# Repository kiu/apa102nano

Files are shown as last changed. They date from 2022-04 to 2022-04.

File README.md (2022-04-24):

# apa102nano
I love to play around with adressable [APA102](https://cpldcpu.wordpress.com/2014/08/27/apa102/) LED strips, quickly iterating animations using the Arduino Nano.
But I am tired of wiring power, looking up which pins are SPI and having dangling wires everywhere. Time to have some boards ready for a frustration free out-of-the-box experience.

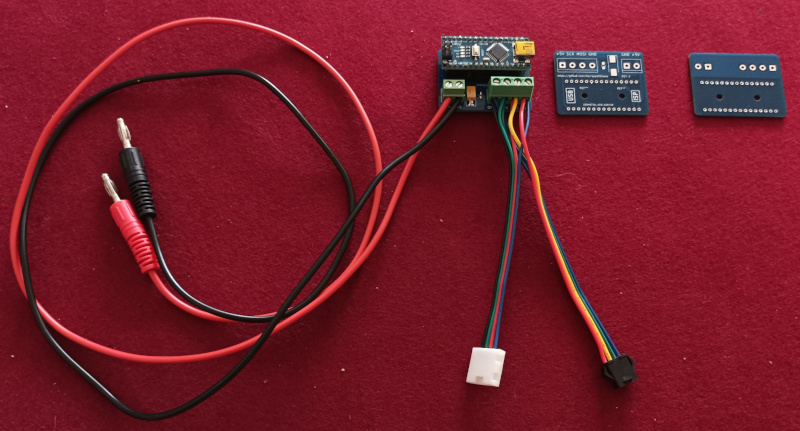
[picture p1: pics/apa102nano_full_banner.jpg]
apa102nano


# Nitty-Gritty Details
Checkout the [pics](https://github.com/kiu/apa102nano/tree/master/pics) and [hardware](https://github.com/kiu/apa102nano/tree/master/rev_a) section including BOM, Schematic, PCB layout, etc.

# Errata
I included mounting holes as an afterthought and forget to hide the silk screen "REF**" designators :/

# License
Creative Commons Attribution-NonCommercial 3.0 Unported (CC BY-NC 3.0)
See LICENSE and https://creativecommons.org/licenses/by-nc/3.0/

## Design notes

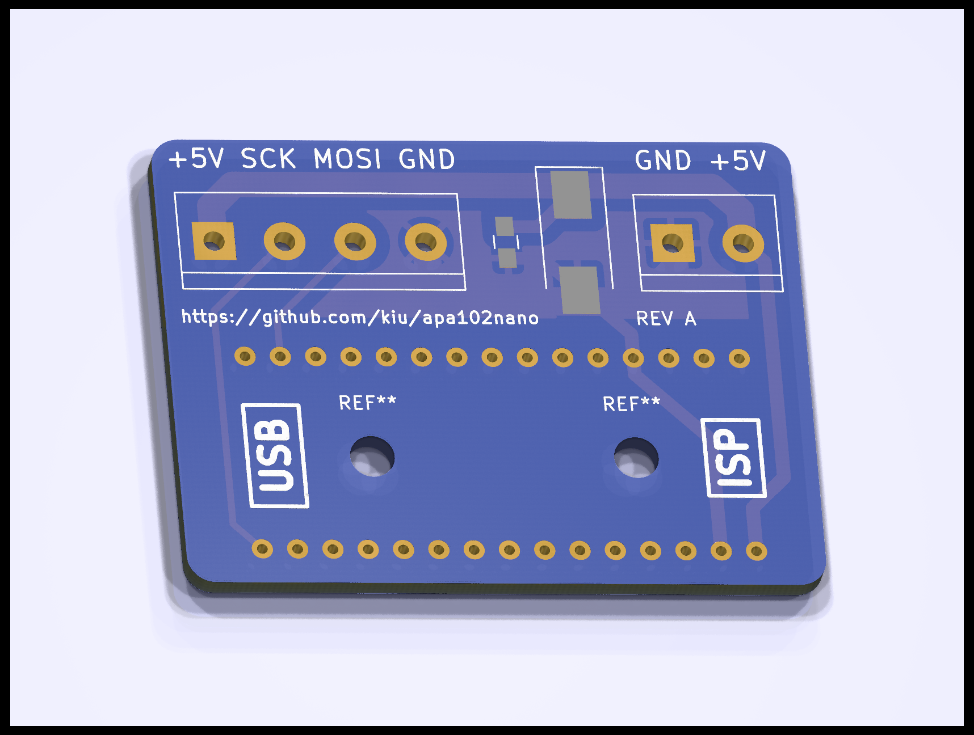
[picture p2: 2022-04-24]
rev_a/hardware/apa102nano-render.png

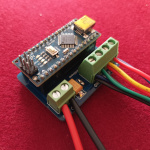
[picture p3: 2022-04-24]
pics/apa102nano_closeup_150x150.jpg

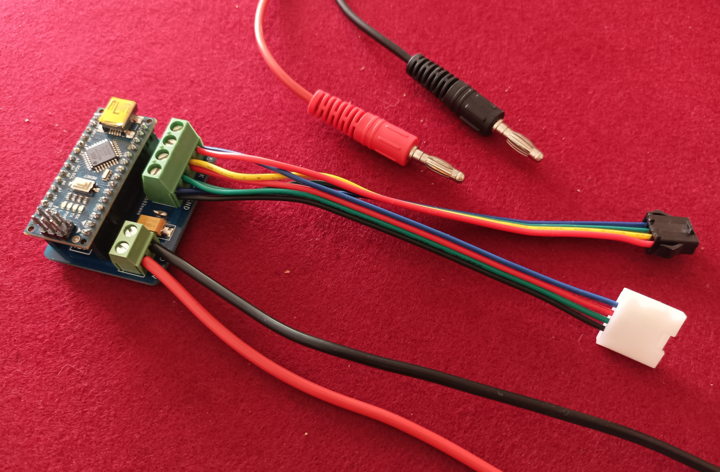
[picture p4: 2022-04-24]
pics/apa102nano_connectors.jpg

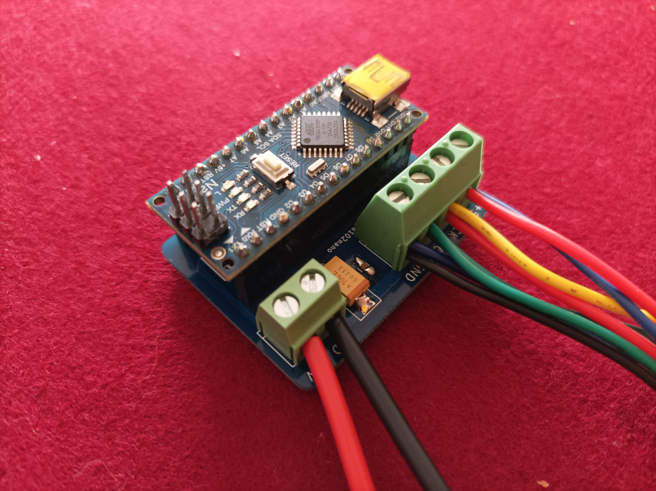
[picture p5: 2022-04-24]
pics/apa102nano_closeup.jpg

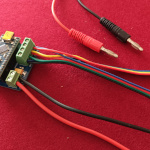
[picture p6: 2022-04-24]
pics/apa102nano_connectors_150x150.jpg

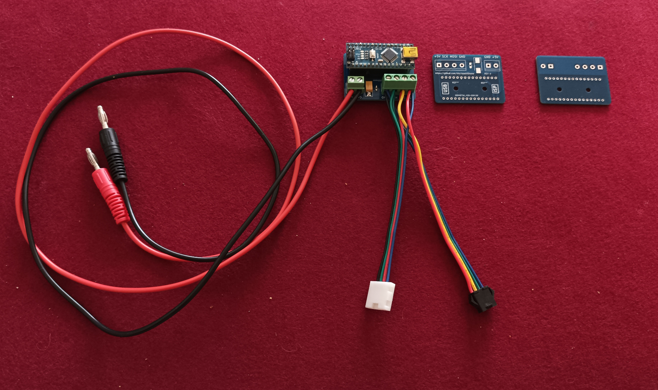
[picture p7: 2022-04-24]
pics/apa102nano_full.jpg

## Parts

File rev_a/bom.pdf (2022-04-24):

BOM

Page 1

Symbol | Description | Req | +VAT | Price | Price (sum) | Provider | ID
| | | | MOQ 10
A1 | Pin Header 1x15 2.54 | 2 | 0 | 0,14 € | 0,27 € | https://www.aliexpress.com | 4000220585291
J1 | Terminal Block 1x02 P5.08 | 1 | 0 | 0,25 € | 0,25 € | http://www.reichelt.de | CTB0509-2
J2 | Terminal Block 1x04 P5.08 | 1 | 0 | 1,54 € | 1,54 € | http://tme.eu | MKDS1.5/4-5.08
C1 | 220uF Tantalum Case D | 1 | 19 | 0,80 € | 0,95 € | http://www.mouser.de | 74-293D227X96R3D2TE3
C2 | 100nF 0805 | 1 | 19 | 0,07 € | 0,08 € | http://www.mouser.de | 710-885012207098
- | PCB 46x35 Blue + Shipping | 1 | 19 | 1,41 € | 1,67 € | https://jlcpcb.com | -

SUM
4,77 €
47,68 €

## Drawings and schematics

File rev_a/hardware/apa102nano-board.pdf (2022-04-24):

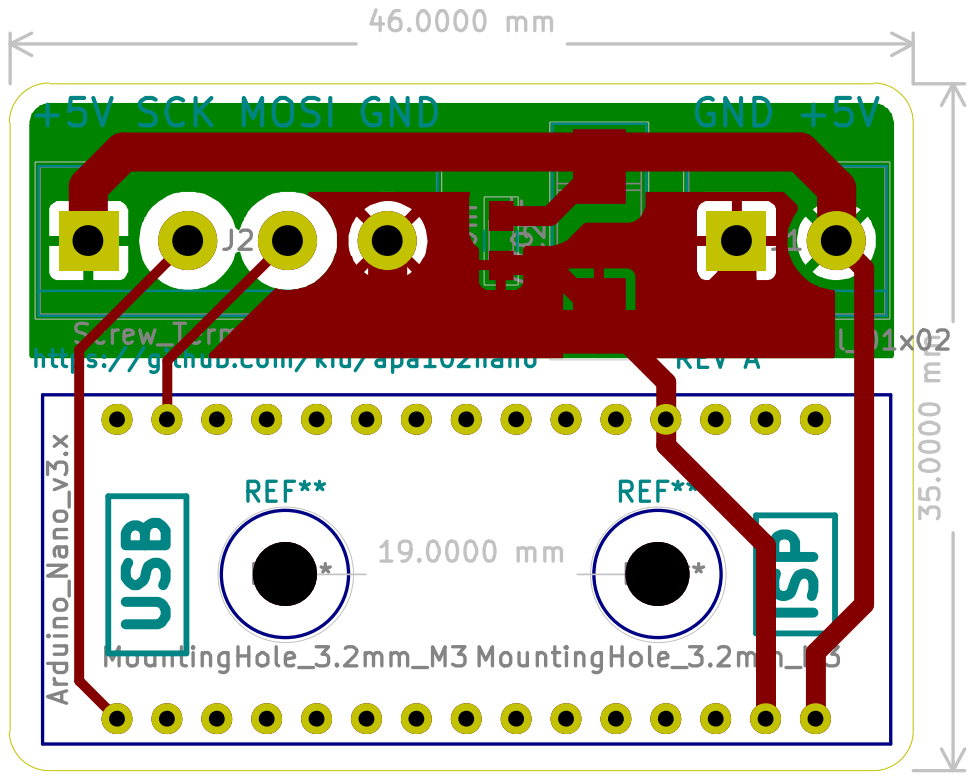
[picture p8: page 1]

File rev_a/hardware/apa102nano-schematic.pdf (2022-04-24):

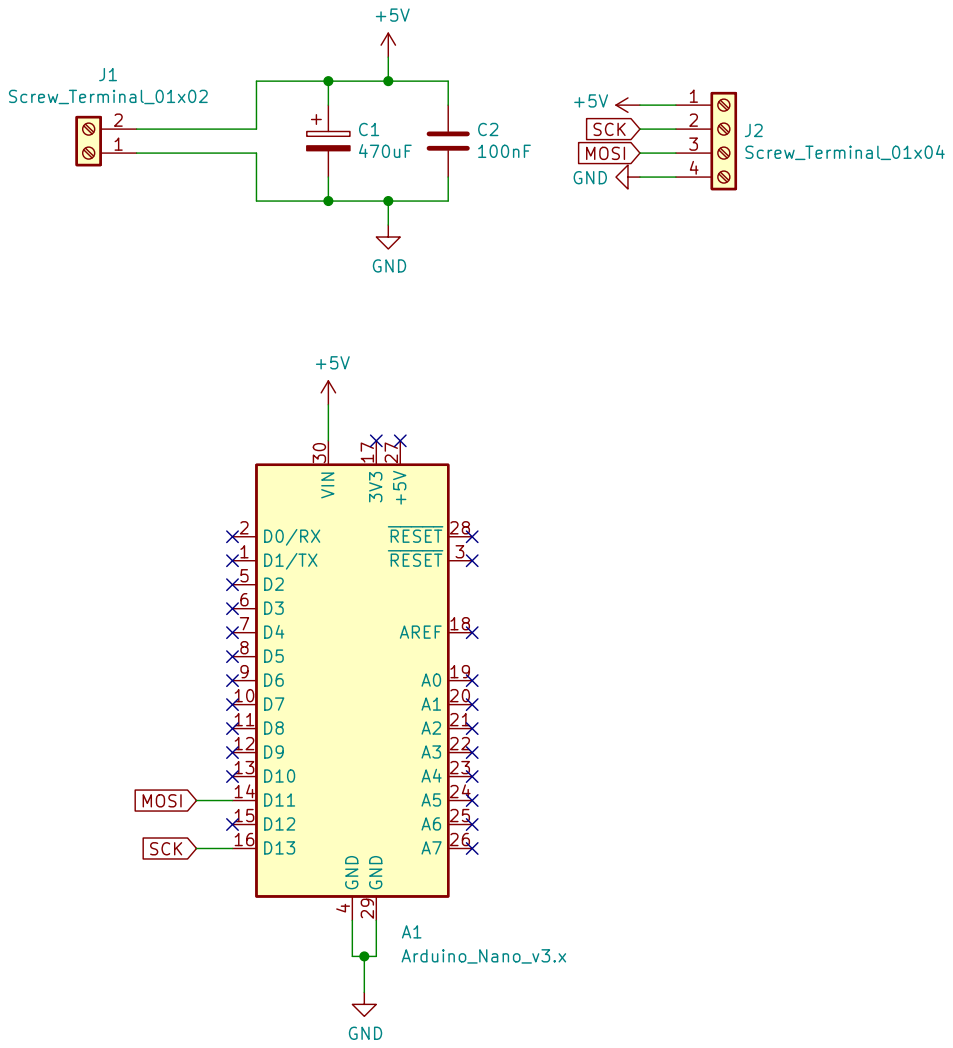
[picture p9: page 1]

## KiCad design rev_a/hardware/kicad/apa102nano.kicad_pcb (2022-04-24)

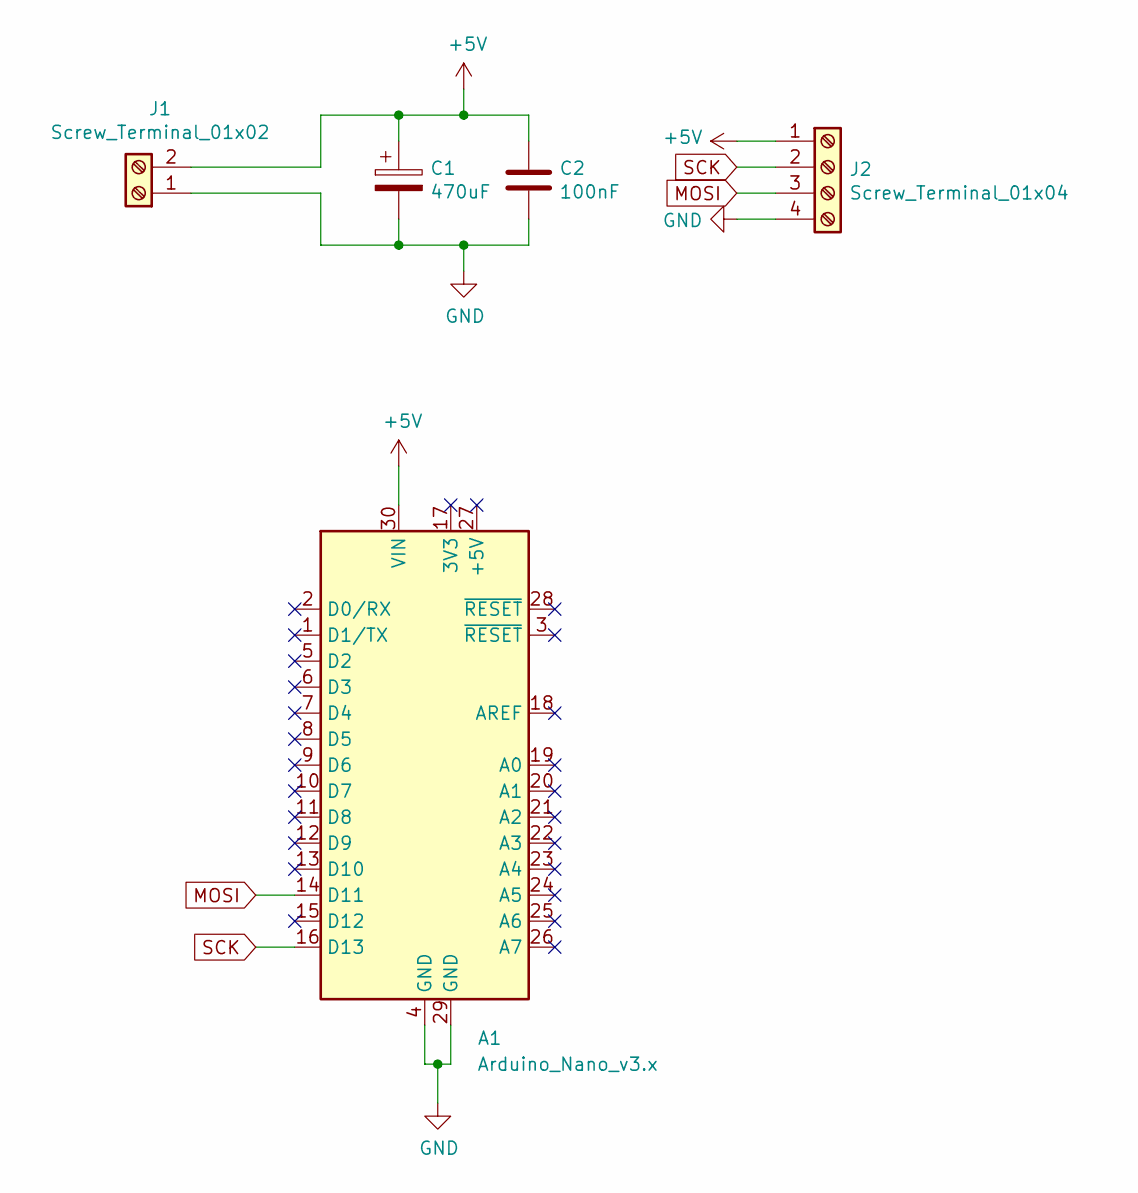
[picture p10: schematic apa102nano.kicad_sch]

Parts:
A1: Arduino_Nano_v3.x; Arduino_Nano
C1: 470uF; CP_Tantalum_Case-D_EIA-7343-31_Hand
C2: 100nF; C_0805_HandSoldering
J1: Screw_Terminal_01x02; TerminalBlock_bornier-2_P5.08mm
J2: Screw_Terminal_01x04; TerminalBlock_bornier-4_P5.08mm

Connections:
+5V: A1.30 (VIN), C1.1, C2.1, J1.2, J2.1
GND: A1.4 (GND), A1.29 (GND), C1.2, C2.2, J1.1, J2.4
MOSI: A1.14 (D11), J2.3
SCK: A1.16 (D13), J2.2

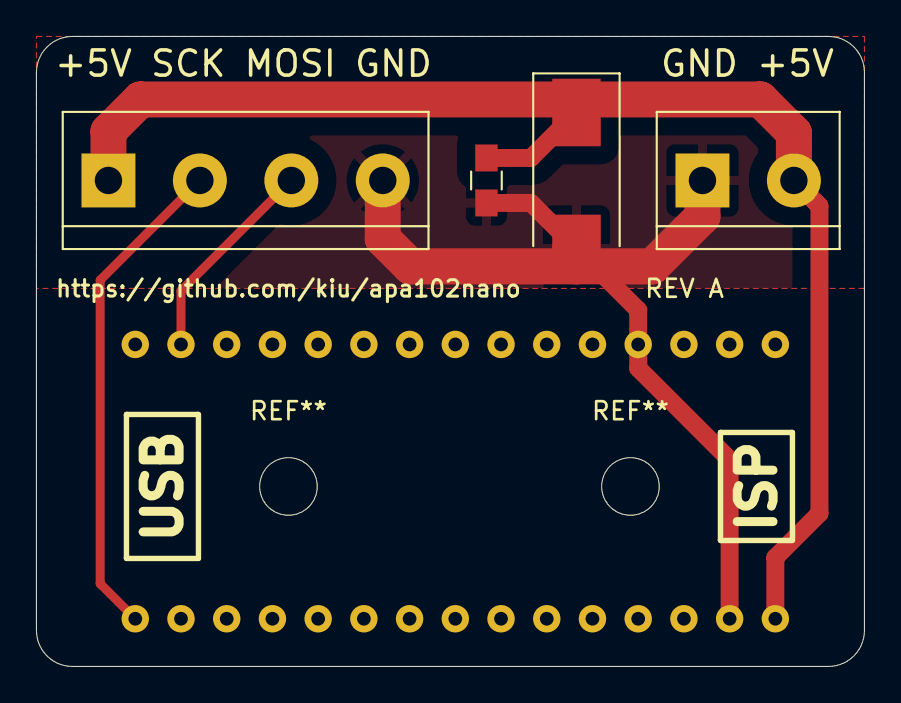
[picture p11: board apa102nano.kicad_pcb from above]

Board: 2 copper layers, 46.0 x 35.0 mm, 5 parts (0 on the bottom side), 4 nets.
